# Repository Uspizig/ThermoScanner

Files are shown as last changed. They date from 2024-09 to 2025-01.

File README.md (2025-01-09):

# ThermoScanner: The Programmable Scanner for your K-Type Thermo Sensors with Display and Audio

<p align="center">
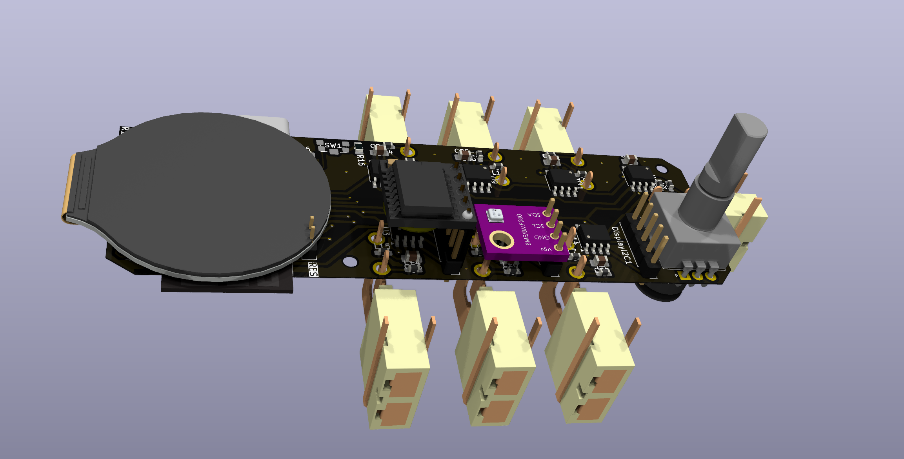
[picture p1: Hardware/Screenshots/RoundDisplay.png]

</p>

## Features:

1. **AudioAmplifier MAX98357**: Listen to your favourite Tunes with an Audio Amplifier

2. **7 or 8 x K - Type Connectors** Perfect for measuring your heating system

3. **Max31855 or Max31856 Thermo Sensors** High precision

4. **I2C Connector for Sensor**: Connect your favourite I2C Sensor board with the embedded 2.54mm connector

5. **MicroSD Card**: Perfect for storing your thermo logger Data

6. **Wireless Control**: Untehther your development process with the wireless capabilities. With WiFi and BLE, this tool allows remote control and data logging. Users can adjust settings and monitor data from a distance, offering a more flexible development experience.

7. **Open Source & Programmable**: As an open-source device, the Device offers unmatched versatility. It is fully programmable, allowing you to tailor its functionality to your specific applications. This customization extends to software and hardware, opening up endless possibilities for creative and efficient project development.

8. **Compact Design**: Designed for convenience, the Thermologger Board compact and sleek form factor allows for seamless integration into existing setups. Its compatibility with USB PD sources and inline integration capability minimizes the need for additional equipment or extensive redesign, making it a versatile and user-friendly addition to any development environment.

9. **Display**: Monitor live the current status of all Thermo Logger sources or I2C Sensors

10. **Jog Dial** for operating the Device

<p align="center">
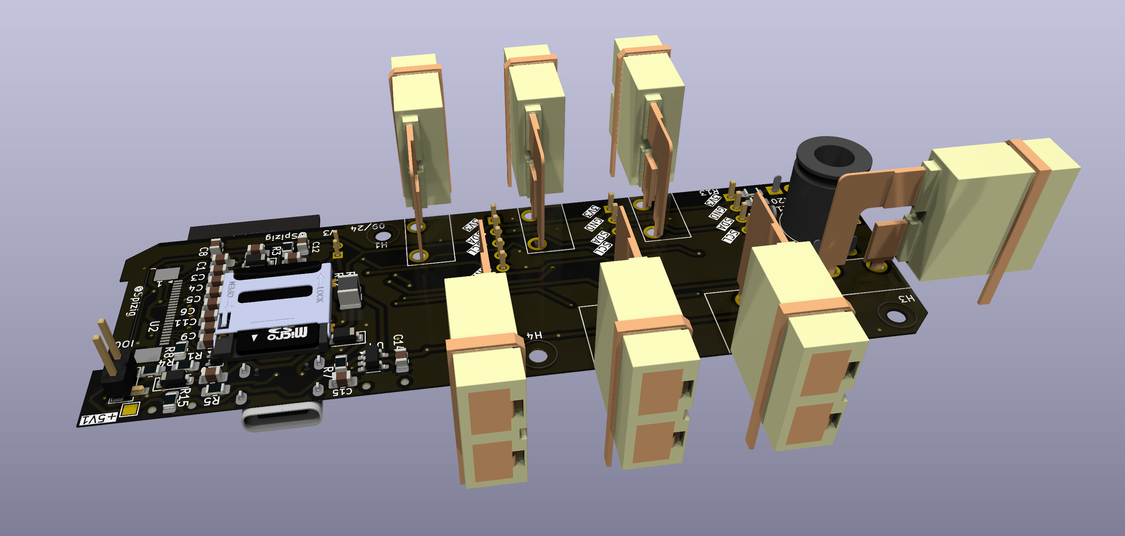
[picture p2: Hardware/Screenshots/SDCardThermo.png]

</p>

9. **RGB LED**: Status LED
## Specifications

<p align="center">
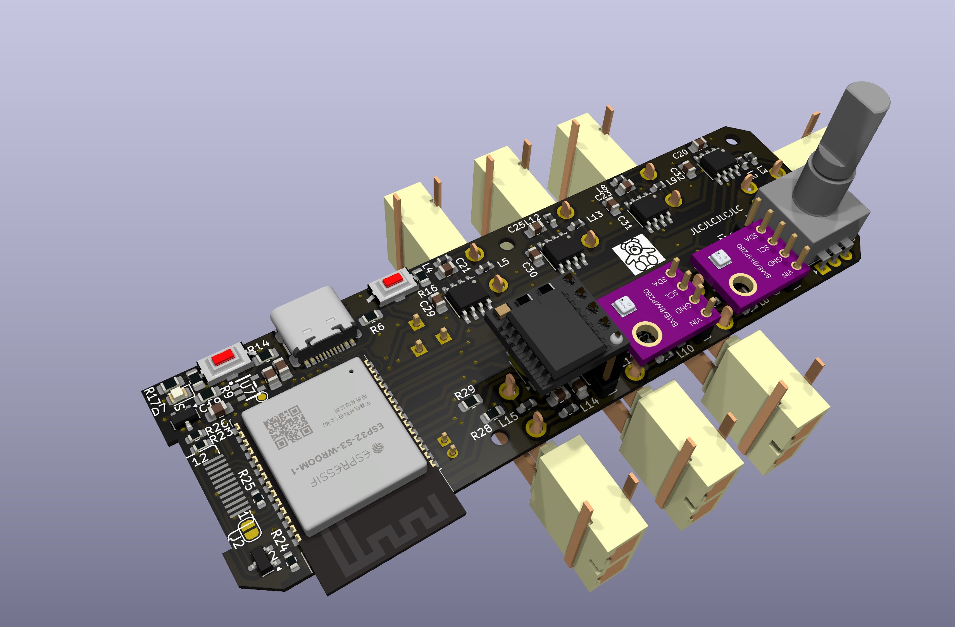
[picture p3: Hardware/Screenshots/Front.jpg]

</p>

<p align="center">
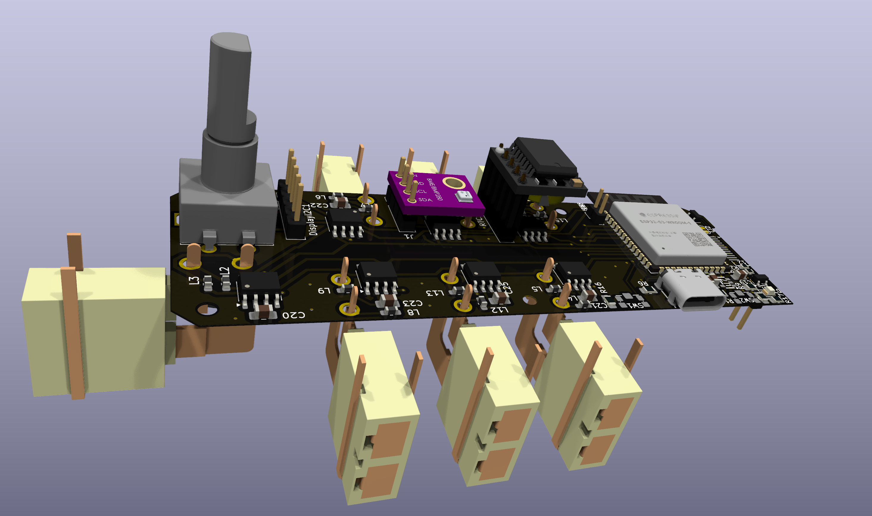
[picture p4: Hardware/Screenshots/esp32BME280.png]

</p>

### Key Features:

### Future Developments:
1. Home Assistant integration

2. Eink Display for Power Saving
<p align="center">
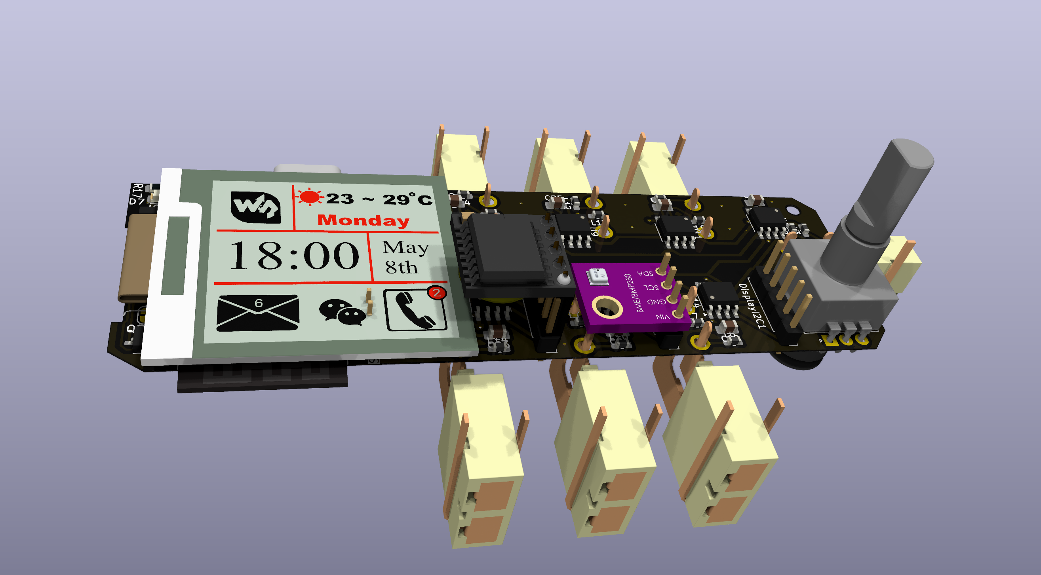
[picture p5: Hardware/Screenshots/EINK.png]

</p>

## Testing for Performance

At the heart of ThermoLogger's design is a commitment to reliability and performance. To ensure that SenseLoRaCam stands up to real-world demands, we subjected it to testing under use conditions.

## License

MIT License

Copyright (c) 2025 blue2monster

Permission is hereby granted, free of charge, to any person obtaining a copy
of this software and associated documentation files (the "Software"), to deal
in the Software without restriction, including without limitation the rights
to use, copy, modify, merge, publish, distribute, sublicense, and/or sell
copies of the Software, and to permit persons to whom the Software is
furnished to do so, subject to the following conditions:

The above copyright notice and this permission notice shall be included in all
copies or substantial portions of the Software.

THE SOFTWARE IS PROVIDED "AS IS", WITHOUT WARRANTY OF ANY KIND, EXPRESS OR
IMPLIED, INCLUDING BUT NOT LIMITED TO THE WARRANTIES OF MERCHANTABILITY,
FITNESS FOR A PARTICULAR PURPOSE AND NONINFRINGEMENT. IN NO EVENT SHALL THE
AUTHORS OR COPYRIGHT HOLDERS BE LIABLE FOR ANY CLAIM, DAMAGES OR OTHER
LIABILITY, WHETHER IN AN ACTION OF CONTRACT, TORT OR OTHERWISE, ARISING FROM,
OUT OF OR IN CONNECTION WITH THE SOFTWARE OR THE USE OR OTHER DEALINGS IN THE
SOFTWARE.

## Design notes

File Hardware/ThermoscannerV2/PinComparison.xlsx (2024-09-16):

ESP32-C6 | WROOM |  | ESP32-S3 | WROOM
Pin Number | Funktion | Besonderheiten | Pin Number |  | SmartKnob Function
1 | GND |  | 1 | GND
2 | 3V3 |  | 2 | 3V3
3 | EN |  | 3 | EN
4 | IO4 |  | 4 | IO4 | LORA DIO2 | HEADER
5 | IO5 |  | 5 | IO5 | LORA DIO5 | HEADER
6 | IO6 |  | 6 | IO6 | Header
7 | IO7 |  | 7 | IO7 | Header
8 | IO0 |  | 8 | IO15 | LORA RES | AUDIO SD2
9 | IO1 |  | 9 | IO16 | AUDIO SD
10 | IO8 | Strapping Pin | 10 | IO17 | AUDIO DIN
11 | IO10 |  | 11 | IO18 | AUDIO BCLK
12 | IO11 |  | 12 | IO8 | AUDIO LRC
13 | IO12 |  | 13 | IO19 | USB D-
14 | IO13 |  | 14 | IO20 | USB D+
 |  |  | 15 | IO3 | BUTTON 2
 |  |  | 16 | IO46 | x
 |  |  | 17 | IO9 | xxxx
 |  |  | 18 | IO10 | LORA CS
 |  |  | 19 | IO11 | LORA CLK
 |  |  | 20 | IO12 | LORA MOSI
 |  |  | 21 | IO13 | Button 1
 |  |  | 22 | IO14 | EPD RST
 |  |  | 23 | IO21 | EPD BUSY | J9 hinzu
 |  |  | 24 | IO47 | JP1
 |  |  | 25 | IO48 | x
 |  |  | 26 | IO45 | TP3
15 | IO9 | IO0 | 27 | IO0 | IO0
16 | IO18 | EPD_BU2 | 28 | IO35 | SPARE IO
17 | IO19 |  | 29 | IO36 | SPARE IO
18 | IO20 |  | 30 | IO37 | SPAREIO
19 | IO21 |  | 31 | IO38 | EPD_DC
20 | IO22 |  | 32 | IO39 | EPD CS
21 | IO23 |  | 33 | IO40 | EPD CLK
22 | NC |  | 34 | IO41 | EPD MOSI
23 | IO15 | JTAG SIGNAL | 35 | IO42 | LORA MISO | Fixed with J8
24 | RXD |  | 36 | RXD | RXD
25 | TXD |  | 37 | TXD | RXD
26 | IO3 | WS2812 | 38 | IO2 | Header
27 | IO2 | BLK | 39 | IO1 | Header
28 | GND |  | 40 | GND

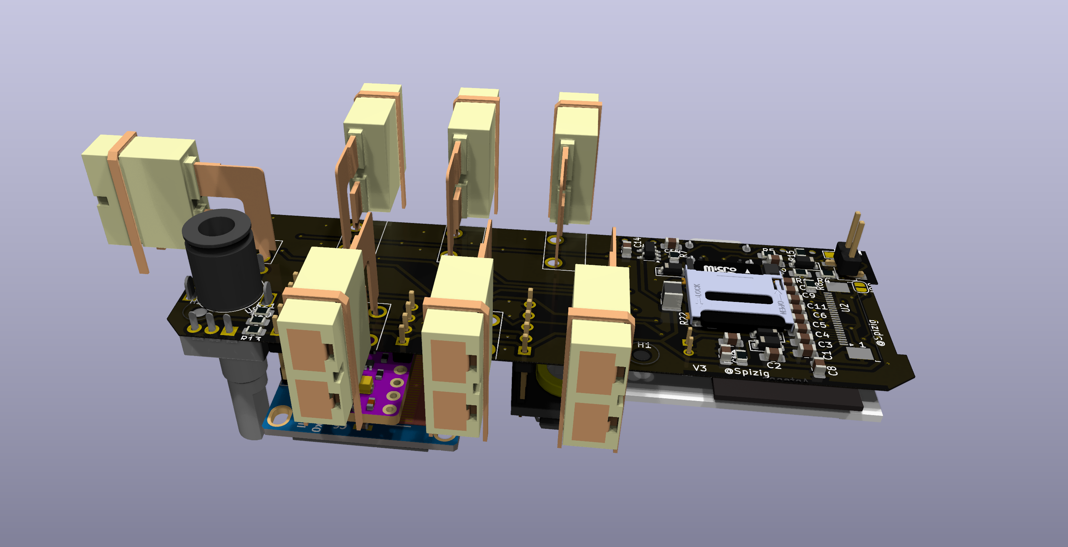
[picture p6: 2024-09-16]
Hardware/Screenshots/MicroSD.png

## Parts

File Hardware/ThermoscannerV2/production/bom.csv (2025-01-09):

Designator | Footprint | Quantity | Value | LCSC Part #
+5V | TestPoint_Pad_1.5x1.5mm | 1 | TestPoint
BAT | PinHeader_1x02_P2.54mm_Vertical_SMD_Pin1Left | 1 | PWR
C1, C11, C2, C3, C4, C5, C6, C7, C9 | 0805 | 9 | 105
C10, C12, C14, C15, C16, C21 | 0805 | 6 | 4.7uF50V
C13, C17, C18, C19, C20, C22, C23, C24, C25, C26, C27, C28, C29, C30, C31, C32, C33, C34 | 0805 | 18 | 100nF
C8 | 0805 | 1 | 104
D1, D11, D2, D3, D8 | D_SOD-123 | 5 | MBR0530
D10, D12, D13, D14, D4, D5, D6, D9 | LED_WS2812B_PLCC4_5.0x5.0mm_P3.2mm | 8 | WS2812B
D15, D16, D17, D18, D19, D20, D21, D22 | MX_SK6812MINI-E | 8 | SK6812MINI-E
D7 | 0805 | 1 | LED
EXT1, INA322 | PinHeader_1x08_P2.54mm_Vertical | 2 | Conn_01x08_Pin
H13, H2, H3, H4, H6, H7 | MountingHole_2.2mm_M2 | 6 | MountingHole
I2C1, RTC1 | PinHeader_1x05_P2.54mm_Vertical | 2 | Conn_01x05_Pin
IO0, J2 | SolderJumper-2_P1.3mm_Open_RoundedPad1.0x1.5mm | 2 | Conn_01x02_Pin
J1, RES | PinHeader_1x02_P2.00mm_Vertical | 2 | Conn_01x02_Pin
J10, J11, J12, J13, J14, J15, J16, J9 | OMEGA_PCC-SMP-V-K | 8 | PCC-SMP-V-K
J3 | TF-SMD_XKTF-0803-0 | 1 | Micro_SD_Card_Det_US
J4 | PinHeader_1x01_P2.54mm_Vertical | 1 | Conn_01x01_Pin
JOG1 | JogWheel | 1 | jogdial
L1 | 1210 | 1 | 68uH1A
Q1 | SOT-323_SC-70 | 1 | Si1308
Q2 | SOT-23 | 1 | 2N7002
R1, R10, R11, R12, R18, R2, R21, R22, R3, R30, R31, R4 | 0805 | 12 | 10K
R13, R15, R16, R17, R28 | 0805 | 5 | 100K
R14, R9 | 0805 | 2 | 1K
R19 | 0805 | 1 | 300K
R20 | 0805 | 1 | 330k
R23 | 0603 | 1 | 10k
R24 | 0603 | 1 | 1M
R25 | 0603 | 1 | 22
R26 | 0603 | 1 | 0R
R27, R29, R32, R7 | 0805 | 4 | 0R
R5, R6 | 0805 | 2 | 5k11
R8 | 0805 | 1 | 3R
REFTemp1 | PinHeader_1x04_P2.54mm_Vertical | 1 | Conn_01x04_Pin
SI2 | SOT-23 | 1 | SI2301CDS
SW1, SW2 | SW_SPST_CK_KMS2xxGP | 2 | SW_Push
TP1, TP2, TP3 | TestPoint_Pad_D1.0mm | 3 | TestPoint
Therm1 | MLX90640 | 1 | MLX90640
U1 | ESP32-S3-WROOM-1 | 1 | ESP32-S3-WROOM-1-Espressif
U11, U4 | SOT-23-5 | 2 | RT9013
U2 | TE_2-1734839-4_1x24-1MP_P0.5mm_Horizontal | 1 | FPCConn
U3 | TSSOP-16_4.4x5mm_P0.65mm | 1 | TCA9554PW
U5 | TSSOP-14_4.4x5mm_P0.65mm | 1 | MAX31856
U6 | GC9A01_IPS_display_reversed | 1 | GC9A01_IPS_display
U7 | SOT-23-5_L3.0-W1.7-P0.95-LS2.8-BR | 1 | TP4065
U8 | TSSOP-28_4.4x9.7mm_P0.65mm | 1 | ADG1607xCP
U9 | TQFN-16_L3.0-W3.0-P0.50-BL-EP1.5 | 1 | ~
USB | USB-C_SMD-TYPE-C-31-M-12 | 1 | KoreanHropartsElecTYPE-C-31-M-12

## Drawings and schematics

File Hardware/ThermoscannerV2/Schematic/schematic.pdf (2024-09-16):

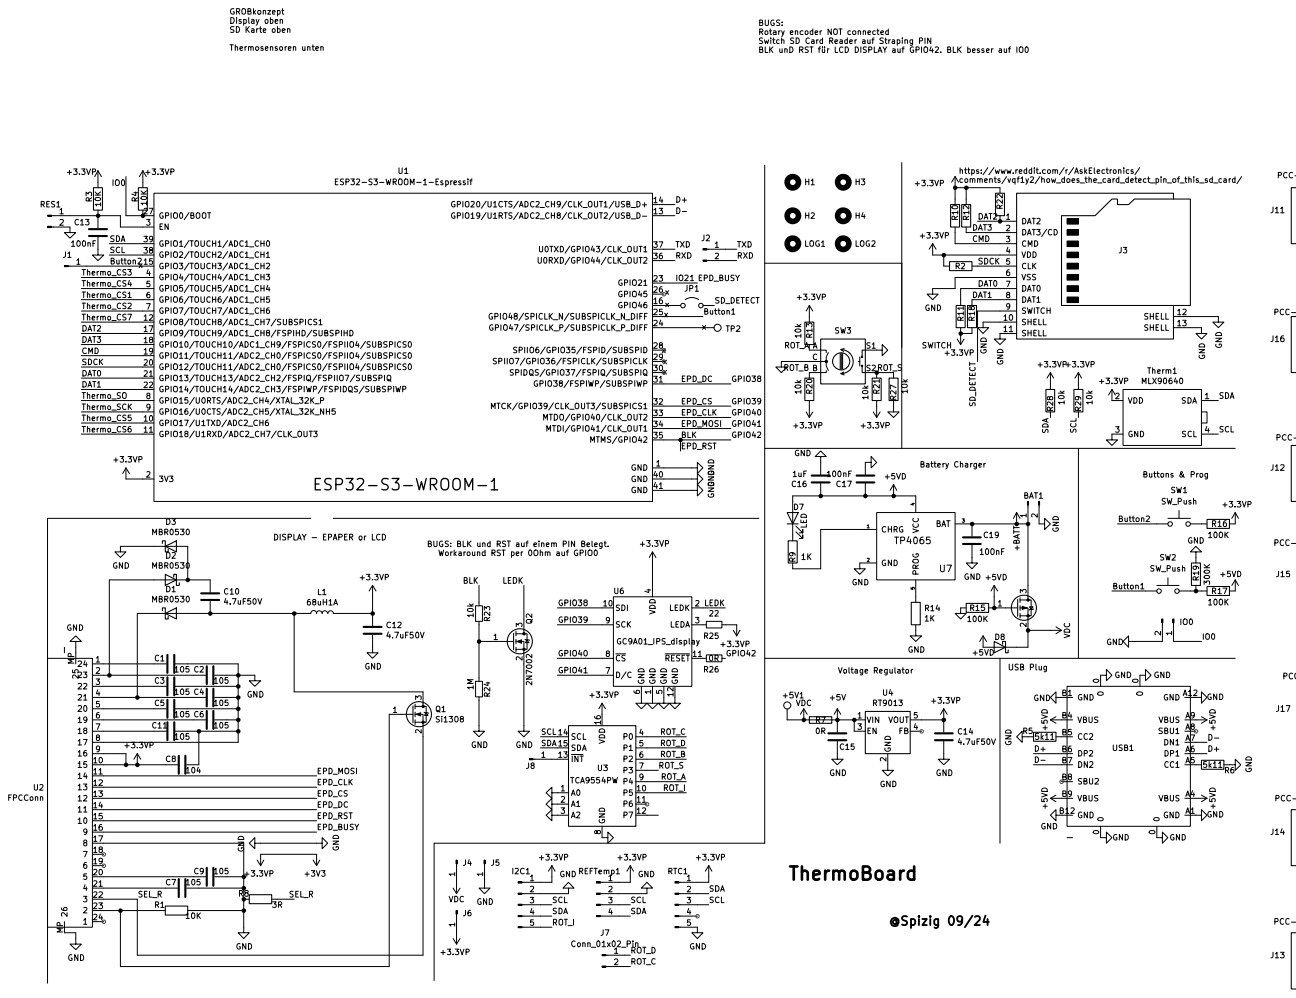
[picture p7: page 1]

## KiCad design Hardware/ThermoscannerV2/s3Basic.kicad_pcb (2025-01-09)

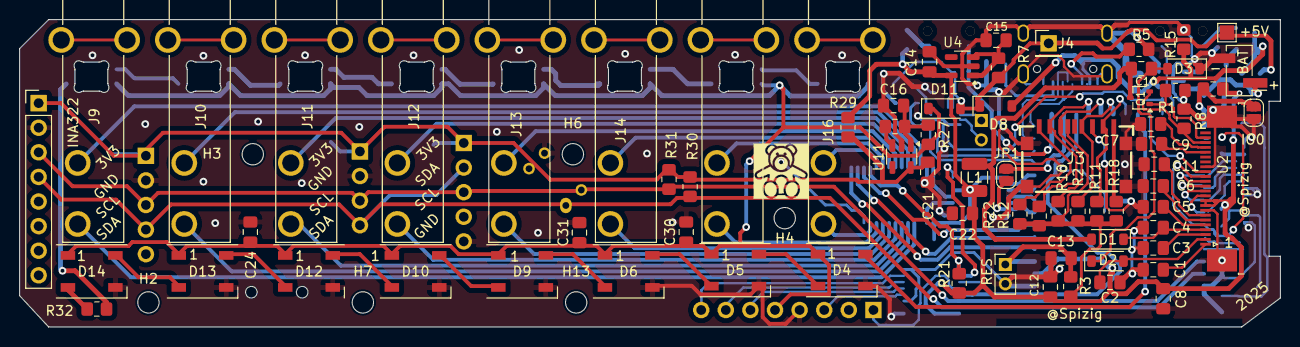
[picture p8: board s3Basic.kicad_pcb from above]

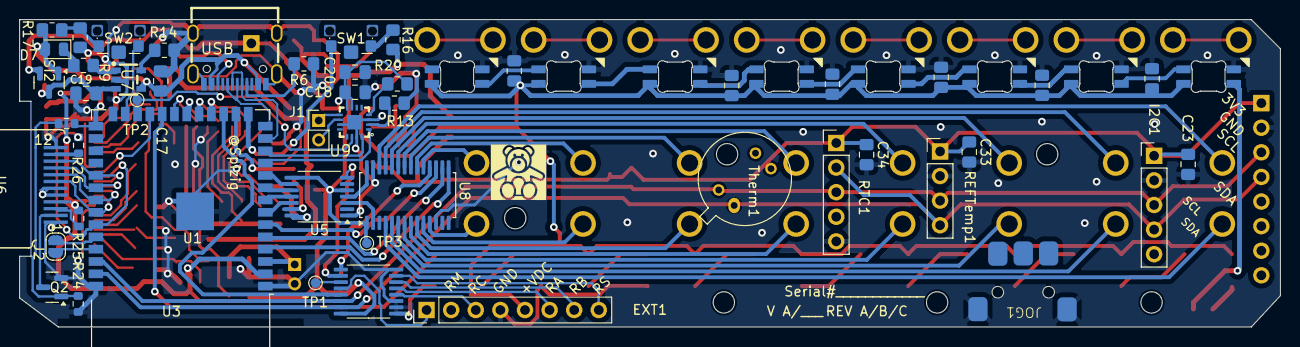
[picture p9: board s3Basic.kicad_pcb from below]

Board: 2 copper layers, 130.2 x 31.7 mm, 140 parts (50 on the bottom side), 124 nets.

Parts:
+5V: TestPoint; TestPoint_Pad_1.5x1.5mm
BAT: PWR; PinHeader_1x02_P2.54mm_Vertical_SMD_Pin1Left
C1, C2, C3, C4, C5, C6, C7, C9, C11: 105; C_0805_2012Metric_Pad1.18x1.45mm_HandSolder
C8: 104; C_0805_2012Metric_Pad1.18x1.45mm_HandSolder
C10, C12, C14, C15, C16, C21: 4.7uF50V; C_0805_2012Metric_Pad1.18x1.45mm_HandSolder
C13, C17, C18, C19, C20, C22, C23, C24, C25, C26, C27, C28, C29, C30, C31, C32, C33, C34: 100nF; C_0805_2012Metric_Pad1.18x1.45mm_HandSolder
D1, D2, D3, D8, D11: MBR0530; D_SOD-123
D4, D5, D6, D9, D10, D12, D13, D14: WS2812B; LED_WS2812B_PLCC4_5.0x5.0mm_P3.2mm
D7: LED; LED_0805_2012Metric
D15, D16, D17, D18, D19, D20, D21, D22: SK6812MINI-E; MX_SK6812MINI-E
EXT1: Conn_01x08_Pin; PinHeader_1x08_P2.54mm_Vertical
H2, H3, H4, H6, H7, H13: MountingHole; MountingHole_2.2mm_M2
I2C1: Conn_01x05_Pin; PinHeader_1x05_P2.54mm_Vertical
INA322: Conn_01x08_Pin; PinHeader_1x08_P2.54mm_Vertical
IO0: Conn_01x02_Pin; SolderJumper-2_P1.3mm_Open_RoundedPad1.0x1.5mm
J1: Conn_01x02_Pin; PinHeader_1x02_P2.00mm_Vertical
J2: Conn_01x02_Pin; SolderJumper-2_P1.3mm_Open_RoundedPad1.0x1.5mm
J3: Micro_SD_Card_Det_US; TF-SMD_XKTF-0803-0
J4: Conn_01x01_Pin; PinHeader_1x01_P2.54mm_Vertical
J9, J10, J11, J12, J13, J14, J15, J16: PCC-SMP-V-K; OMEGA_PCC-SMP-V-K
JOG1: jogdial; JogWheel
JP1: SolderJumper_2_Open; SolderJumper-2_P1.3mm_Open_RoundedPad1.0x1.5mm
L1: 68uH1A; L_1210_3225Metric
LOG1, LOG2: MountingHole; baerklein
Q1: Si1308; SOT-323_SC-70
Q2: 2N7002; SOT-23
R1, R3, R4: 10K; R_0805_2012Metric_Pad1.20x1.40mm_HandSolder
R2, R10, R11, R12, R18, R21, R22, R30, R31: 10k; R_0805_2012Metric_Pad1.20x1.40mm_HandSolder
R5, R6: 5k11; R_0805_2012Metric_Pad1.20x1.40mm_HandSolder
R7, R27, R29, R32: 0R; R_0805_2012Metric_Pad1.20x1.40mm_HandSolder
R8: 3R; R_0805_2012Metric_Pad1.20x1.40mm_HandSolder
R9, R14: 1K; R_0805_2012Metric_Pad1.20x1.40mm_HandSolder
R13, R15, R16, R17, R28: 100K; R_0805_2012Metric_Pad1.20x1.40mm_HandSolder
R19: 300K; R_0805_2012Metric_Pad1.20x1.40mm_HandSolder
R20: 330k; R_0805_2012Metric_Pad1.20x1.40mm_HandSolder
R23: 10k; R_0603_1608Metric
R24: 1M; R_0603_1608Metric
R25: 22; R_0603_1608Metric
R26: 0R; R_0603_1608Metric
REFTemp1: Conn_01x04_Pin; PinHeader_1x04_P2.54mm_Vertical
RES: Conn_01x02_Pin; PinHeader_1x02_P2.00mm_Vertical
RTC1: Conn_01x05_Pin; PinHeader_1x05_P2.54mm_Vertical
SI2: SI2301CDS; SOT-23
SW1, SW2: SW_Push; SW_SPST_CK_KMS2xxGP
TP1, TP2, TP3: TestPoint; TestPoint_Pad_D1.0mm
Therm1: MLX90640
U1: ESP32-S3-WROOM-1-Espressif; ESP32-S3-WROOM-1
U2: FPCConn; TE_2-1734839-4_1x24-1MP_P0.5mm_Horizontal
U3: TCA9554PW; TSSOP-16_4.4x5mm_P0.65mm
U4, U11: RT9013; SOT-23-5
U5: MAX31856; TSSOP-14_4.4x5mm_P0.65mm
U6: GC9A01_IPS_display; GC9A01_IPS_display_reversed
U7: TP4065; SOT-23-5_L3.0-W1.7-P0.95-LS2.8-BR
U8: ADG1607xCP; TSSOP-28_4.4x9.7mm_P0.65mm
U9: TQFN-16_L3.0-W3.0-P0.50-BL-EP1.5
USB: KoreanHropartsElecTYPE-C-31-M-12; USB-C_SMD-TYPE-C-31-M-12

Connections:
+3.3VA: C21.2, C23.1, C33.1, C34.1, I2C1.1, INA322.1, R29.1, R30.2, R31.2, REFTemp1.1, RTC1.1, Therm1.2 (VDD), U11.5 (VOUT)
+3.3VP: C8.2, C12.2, C14.2, C22.2, J3.4 (VDD), L1.2, R2.1, R3.2, R4.2, R10.1, R11.2, R12.1, R16.1, R18.2, R21.2, R22.1, R25.2, R29.2, TP3.1, U1.2 (3V3), U2.9 (16), U2.10 (15), U3.16 (VDD), U4.5 (VOUT), U5.5 (AVDD), U5.8 (DVDD), U6.4 (VDD), U8.1 (V_{DD})
+4V: C24.1, C25.1, C26.1, C27.1, C28.1, C29.1, C30.1, C31.1, C32.1, D4.1 (VDD), D5.1 (VDD), D6.1 (VDD), D9.1 (VDD), D10.1 (VDD), D11.1 (K), D12.1 (VDD), D13.1 (VDD), D14.1 (VDD), D15.1 (VDD), D16.1 (VDD), D17.1 (VDD), D18.1 (VDD), D19.1 (VDD), D20.1 (VDD), D21.1 (VDD), D22.1 (VDD), EXT1.5, R27.2
+5V: C15.2, R7.1, U4.1 (VIN), U4.3 (EN)
+5VD: C17.1, D7.2 (A), D8.2 (A), R15.1, R17.1, SI2.1 (G), U7.4 (VCC), USB.A4 (VBUS), USB.A9 (VBUS), USB.B4 (VBUS), USB.B9 (VBUS)
+BATT: BAT.1, C19.2, SI2.3 (D), U7.3 (BAT)
/Audio_BCLK: U1.12 (GPIO8/TOUCH8/ADC1_CH7/SUBSPICS1), U9.16 (BCLK)
/Audio_DIN: U1.11 (GPIO18/U1RXD/ADC2_CH7/CLK_OUT3), U9.1 (DIN)
/Audio_LRC: TP2.1, U1.24 (GPIO47/SPICLK_P/SUBSPICLK_P_DIFF), U9.14 (LRCLK)
/BLK: IO0.1, R4.1, R23.2, U1.27 (GPIO0/BOOT)
/Button1: SW2.1, U1.25 (GPIO48/SPICLK_N/SUBSPICLK_N_DIFF)
/Button2: SW1.2, U1.15 (GPIO3/TOUCH3/ADC1_CH2)
/CMD: J3.3 (CMD), R10.2, U1.19 (GPIO11/TOUCH11/ADC2_CH0/FSPICS0/FSPIIO4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)
/D+: U1.14 (GPIO20/U1CTS/ADC2_CH9/CLK_OUT1/USB_D+), USB.A6 (DP1), USB.B6 (DP2)
/D-: U1.13 (GPIO19/U1RTS/ADC2_CH8/CLK_OUT2/USB_D-), USB.A7 (DN1), USB.B7 (DN2)
/DAT0: J3.7 (DAT0), R11.1, U1.21 (GPIO13/TOUCH13/ADC2_CH2/FSPIQ/FSPIIO7/S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)
/DAT1: J3.8 (DAT1), R18.1
/DAT3: J3.2 (DAT3/CD), R12.2, U1.18 (GPIO10/TOUCH10/ADC1_CH9/FSPICS0/FSPIIO4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)
/DIS_RES: R26.2, U1.35 (MTMS/GPIO42), U2.15 (10)
/EPD_BUSY: U1.23 (GPIO21), U2.16 (9)
/EPD_CLK: U1.33 (MTDO/GPIO40/CLK_OUT2), U2.12 (13), U6.8 (~CS)
/EPD_CS: U1.32 (MTCK/GPIO39/CLK_OUT3/SUBSPICS1), U2.13 (12), U6.9 (SCK)
/EPD_DC: U1.31 (GPIO38/FSPIWP/SUBSPIWP), U2.14 (11), U6.10 (SDI)
/EPD_MOSI: U1.34 (MTDI/GPIO41/CLK_OUT1), U2.11 (14), U6.7 (D/C)
/GPIO_INT: U1.17 (GPIO9/TOUCH9/ADC1_CH8/FSPIHD/SUBSPIHD), U3.13 (~INT)
/LEDK: Q2.3 (D), U6.2 (LEDK)
/ROT_A: EXT1.6, JOG1.1, U3.5 (P1)
/ROT_B: EXT1.7, JOG1.3, U3.6 (P2)
/ROT_C: EXT1.3, U3.4 (P0)
/ROT_L: EXT1.2, I2C1.5, TP1.1, U3.11 (P6)
/ROT_M: EXT1.1, U3.12 (P7)
/ROT_S: EXT1.8, JOG1.2, U3.7 (P3)
/RXD: J2.2, U1.36 (U0RXD/GPIO44/CLK_OUT2)
/SCL: I2C1.3, INA322.3, R31.1, REFTemp1.3, RTC1.3, Therm1.4 (SCL), U1.38 (GPIO2/TOUCH2/ADC1_CH1), U3.14 (SCL)
/SDA: I2C1.4, INA322.4, R30.1, REFTemp1.4, RTC1.2, Therm1.1 (SDA), U1.39 (GPIO1/TOUCH1/ADC1_CH0), U3.15 (SDA)
/SDCK: J3.5 (CLK), R2.2, U1.20 (GPIO12/TOUCH11/ADC2_CH0/FSPICS0/FSPIIO4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)
/SEL_R: Q1.2 (S), R8.2, U2.22 (3)
/T+: U5.4 (T+), U8.28 (DA)
/T+1: J16.P (POS), U8.19 (S1A)
/T+2: J15.P (POS), U8.20 (S2A)
/T+3: J14.P (POS), U8.21 (S3A)
/T+4: J13.P (POS), U8.22 (S4A)
/T+5: J12.P (POS), U8.23 (S5A)
/T+6: J11.P (POS), U8.24 (S6A)
/T+7: J10.P (POS), U8.25 (S7A)
/T+8: J9.P (POS), U8.26 (S8A)
/T-: U5.3 (T-), U8.2 (DB)
/T-1: J16.N (NEG), U8.11 (S1B)
/T-2: J15.N (NEG), U8.10 (S2B)
/T-3: J14.N (NEG), U8.9 (S3B)
/T-4: J13.N (NEG), U8.8 (S4B)
/T-5: J12.N (NEG), U8.7 (S5B)
/T-6: J11.N (NEG), U8.6 (S6B)
/T-7: J10.N (NEG), U8.5 (S7B)
/T-8: J9.N (NEG), U8.4 (S8B)
/TXD: J2.1, U1.37 (U0TXD/GPIO43/CLK_OUT1)
/Thermo_CS5: U1.10 (GPIO17/U1TXD/ADC2_CH6), U5.9 (~CS)
/Thermo_Enable: R21.1, U3.9 (P4), U8.18 (EN)
/Thermo_Fault: JP1.2 (B), U5.13 (~FAULT)
/Thermo_Matrix1: U1.6 (GPIO6/TOUCH6/ADC1_CH5), U8.17 (A0)
/Thermo_Matrix2: U1.5 (GPIO5/TOUCH5/ADC1_CH4), U8.16 (A1)
/Thermo_Matrix3: U1.4 (GPIO4/TOUCH4/ADC1_CH3), U8.15 (A2)
/Thermo_RDY: U3.10 (P5), U5.7 (~DRDY)
/Thermo_SCK: U1.9 (GPIO16/U0CTS/ADC2_CH5/XTAL_32K_NH5), U5.10 (SCK)
/Thermo_SI: U1.7 (GPIO7/TOUCH7/ADC1_CH6), U5.12 (SDI)
/Thermo_SO: U1.8 (GPIO15/U0RTS/ADC2_CH4/XTAL_32K_P), U5.11 (SDO)
/WS2812: D4.4 (DIN), U1.22 (GPIO14/TOUCH14/ADC2_CH3/FSPIWP/FSPIDQS/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)
/WS2812OUT: D14.2 (DOUT), R32.1
GND: BAT.2, C1.1, C2.1, C3.1, C4.1, C5.1, C6.1, C7.1, C8.1, C9.1, C11.1, C12.1, C13.1, C14.1, C15.1, C16.1, C17.2, C18.2, C19.1, C20.2, C21.1, C22.1, C23.2, C24.2, C25.2, C26.2, C27.2, C28.2, C29.2, C30.2, C31.2, C32.2, C33.2, C34.2, D3.1 (K), D4.3 (VSS), D5.3 (VSS), D6.3 (VSS), D9.3 (VSS), D10.3 (VSS), D12.3 (VSS), D13.3 (VSS), D14.3 (VSS), D15.3 (VSS), D16.3 (VSS), D17.3 (VSS), D18.3 (VSS), D19.3 (VSS), D20.3 (VSS), D21.3 (VSS), D22.3 (VSS), EXT1.4, I2C1.2, INA322.2, IO0.2, J3.6 (VSS), J3.10 (SHELL), J3.11 (SHELL), J3.12 (SHELL), J3.13 (SHELL), JOG1.4, Q2.2 (S), R1.2, R5.1, R6.1, R8.1, R13.1, R14.2, R15.2, R19.1, R24.1, REFTemp1.2, RES.2, RTC1.5, Therm1.3 (GND), U1.1 (GND), U1.40 (GND), U1.41 (GND), U2.8 (17), U2.17 (8), U2.MP (25), U3.1 (A0), U3.2 (A1), U3.3 (A2), U3.8 (GND), U4.2 (GND), U5.1 (AGND), U5.14 (DGND), U6.1 (GND), U6.5 (GND), U6.6 (GND), U6.12 (GND), U7.2 (GND), U8.12 (GND), U8.27 (V_{SS}), U9.3 (GND), U9.11 (GND), U9.15 (GND), U9.17 (GND), U11.2 (GND), USB.0, USB.A1 (GND), USB.A12 (GND), USB.B1 (GND), USB.B12 (GND)
unnamed: C10.1, D1.2 (A), L1.1, Q1.3 (D)
unnamed: C4.2, D1.1 (K), U2.4 (21)
unnamed: C2.2, D2.2 (A), U2.2 (23)
unnamed: C10.2, D2.1 (K), D3.2 (A)
unnamed: D4.2 (DOUT), D5.4 (DIN)
unnamed: D5.2 (DOUT), D6.4 (DIN)
unnamed: D6.2 (DOUT), D9.4 (DIN)
unnamed: D7.1 (K), R9.1
unnamed: D9.2 (DOUT), D10.4 (DIN)
unnamed: D10.2 (DOUT), D12.4 (DIN)
unnamed: D12.2 (DOUT), D13.4 (DIN)
unnamed: D13.2 (DOUT), D14.4 (DIN)
unnamed: D15.4 (DIN), R32.2
unnamed: D15.2 (DOUT), D16.4 (DIN)
unnamed: D16.2 (DOUT), D17.4 (DIN)
unnamed: D17.2 (DOUT), D18.4 (DIN)
unnamed: D18.2 (DOUT), D19.4 (DIN)
unnamed: D19.2 (DOUT), D20.4 (DIN)
unnamed: D20.2 (DOUT), D21.4 (DIN)
unnamed: D21.2 (DOUT), D22.4 (DIN)
unnamed: J1.1, U9.9 (OUTP)
unnamed: J1.2, U9.10 (OUTN)
unnamed: J3.1 (DAT2), R22.2
unnamed: J9.SH1 (SHIELD), J9.SH2 (SHIELD)
unnamed: J10.SH1 (SHIELD), J10.SH2 (SHIELD)
unnamed: J11.SH1 (SHIELD), J11.SH2 (SHIELD)
unnamed: J12.SH1 (SHIELD), J12.SH2 (SHIELD)
unnamed: J13.SH1 (SHIELD), J13.SH2 (SHIELD)
unnamed: J14.SH1 (SHIELD), J14.SH2 (SHIELD)
unnamed: J15.SH1 (SHIELD), J15.SH2 (SHIELD)
unnamed: J16.SH1 (SHIELD), J16.SH2 (SHIELD)
unnamed: JP1.1 (A), U1.16 (GPIO46)
unnamed: Q1.1 (G), R1.1, U2.23 (2)
unnamed: Q2.1 (G), R23.1, R24.2
unnamed: R16.2, SW1.1
unnamed: R17.2, R19.2, SW2.2
unnamed: C13.2, R3.1, RES.1, U1.3 (EN)
unnamed: C7.2, U2.21 (4)
unnamed: C9.2, U2.20 (5)
unnamed: C11.2, U2.7 (18)
unnamed: C6.2, U2.6 (19)
unnamed: C5.2, U2.5 (20)
unnamed: C3.2, U2.3 (22)
unnamed: C1.2, U2.1 (24)
unnamed: R25.1, U6.3 (LEDA)
unnamed: R26.1, U6.11 (~RESET)
unnamed: R9.2, U7.1 (CHRG)
unnamed: R14.1, U7.5 (PROG)
unnamed: R13.2, U9.2 (GAIN)
unnamed: R20.2, U9.4 (SD)
unnamed: R28.1, U11.3 (EN)
unnamed: C16.2, R27.1, R28.2, U11.1 (VIN)
unnamed: R6.2, USB.A5 (CC1)
unnamed: R5.2, USB.B5 (CC2)
VDC: +5V.1, C18.1, C20.1, D8.1 (K), D11.2 (A), J4.1, R7.2, R20.1, SI2.2 (S), U9.7 (VDD), U9.8 (VDD)
